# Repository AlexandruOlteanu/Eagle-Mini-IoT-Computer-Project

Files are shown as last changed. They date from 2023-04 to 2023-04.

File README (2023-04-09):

<Copyright Alexandru Olteanu, grupa 332CA, alexandruolteanu2001@gmail.com>

    Proiectul a fost unul interesant, nu regret ca am invatat cat de cat cum 
se proiecteaza o placuta. Schema a fost relativ usor de construit, doar 
unele componente precum Pinhead-ul cu 6 pini au trebuit luate din alte 
biblioteci, In rest procesul a mers destuld e ok.
    La construirea board-ului a fost mai mult de lucru, a durat ceva pana
am pus dimensiunile placutei, unde vin gaurile si usb-ul ce iese afara, apoi
punerea strategica a componentelor incat:
    a) sa incapa
    b) condensatoarele sa fie apropiate de pinii majoritatii componentelor la 
care sunt conectati
    c) Fiecare rezistenta sa fie pusa cat mai central intre componentele legate
la ea.
    In continuarea, la tragerea cablurilor a fost nevoie de mai multe rectificari
pana sa ajung la varianta finala, am avut diverse probleme de overlap, fire care
nu mai mergeau trase din cauza altora, etc.
    Per total, o tema faina dar muncitoreasca, thx!

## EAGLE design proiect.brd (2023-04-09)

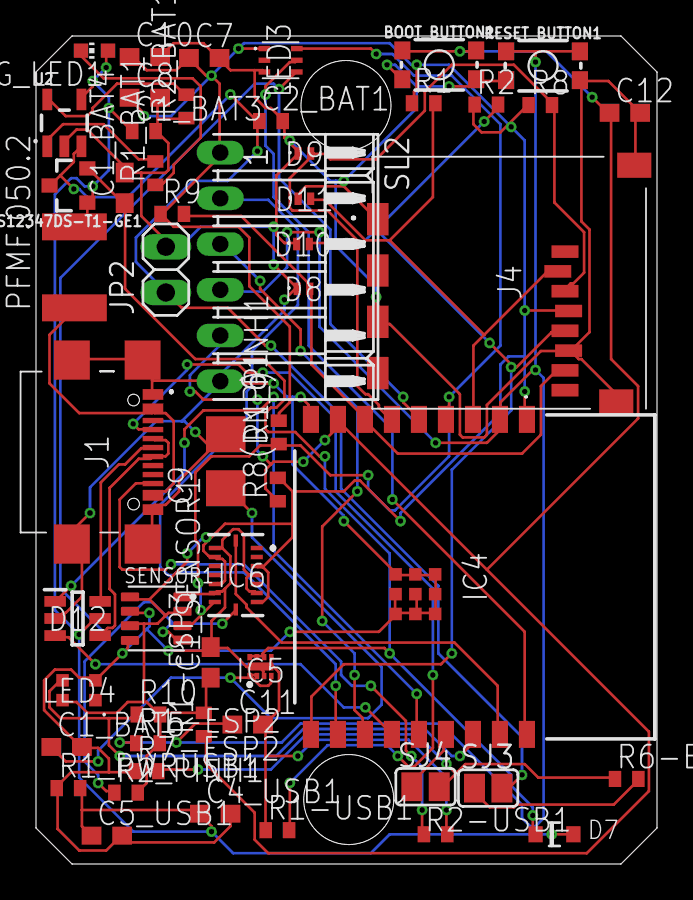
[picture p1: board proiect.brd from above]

Board: 2 copper layers, 34.5 x 46.0 mm, 54 parts (0 on the bottom side), 32 nets.

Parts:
BOOT_BUTTON1: ESP32_WROVER_SPARKFUN-SWITCHES_TACTILE_SWITCH_SMD_4.6X2.8MM
C1_BAT3, C2_BAT1: 4.7uF; ESP32_WROVER_EAGLE-LTSPICE_C0402
C1_BAT4, C1_BAT5, C5_USB1: 4.7uF; ESP32_WROVER_RCL_C0603
C1_SENSOR1, C4_USB1, C7, C8, C10, C12: 100nF; ESP32_WROVER_RCL_C0603
C9: 100uF TANT; RCL_CT3528
C11: 1uF; ESP32_WROVER_RCL_C0603
CHG_LED1: ESP32_WROVER_ADAFRUIT_CHIP-LED0603
D7: ESP32_WROVER_AVX---SD0805S020S1R0_AVX_SD0805S020S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; ESP32_WROVER_AVX---SD0805S020S1R0_AVX_SD0805S020S1R0_0
D8, D9, D10, D11: PESD3V3S1BLYL; SAMACSYS_PARTS_PESD5V0S1BL315
D12: USBLC6-2SC6Y; SAMACSYS_PARTS_SOT95P280X145-6N
IC4: ESP32-C3-WROOM-02-H4; SAMACSYS_PARTS_ESP32C3WROOM02H4
IC5: NCP186BMX330TAG; SAMACSYS_PARTS_NCP186AMX330TAG
IC6: BMI085; SAMACSYS_PARTS_BMI085
J1: USB4110-GF-A; SAMACSYS_PARTS_USB4110GFA
J4: 112A-TAAR-R03_ATTEND; SAMACSYS_PARTS_112ATAARR03ATTEND
JP2: PINHEAD_1X02
LED3: LTR308; ESP32_WROVER_SAMACSYS_PARTS_LTR303ALS01
LED4: WS2812B-2020; SAMACSYS_PARTS_WS2812B2020
PFMF.050.2: 500mA; ESP32_WROVER_VARISTOR_CT/CN1812
R1, R1-ESP2, R1-ESP3, R2, R2_PINH1, R8, R8(DNP)1, R9, R10: 10K; ESP32_WROVER_EAGLE-LTSPICE_R0402
R1-USB1, R2-USB1: 5K1; ESP32_WROVER_EAGLE-LTSPICE_R0402
R1_BAT1: 200; ESP32_WROVER_EAGLE-LTSPICE_R0402
R1_PINH1: 10k; ESP32_WROVER_EAGLE-LTSPICE_R0402
R1_PWRUSB1, R6-ESP2, R7-ESP2: 100K; ESP32_WROVER_EAGLE-LTSPICE_R0402
R2_BAT1: 2K; ESP32_WROVER_EAGLE-LTSPICE_R0402
RESET_BUTTON1: ESP32_WROVER_SPARKFUN-SWITCHES_TACTILE_SWITCH_SMD_4.6X2.8MM
S12347DS-T1-GE1: 20V/4.2A/52mΩ/1.4W; ESP32_WROVER_SPARKFUN-DISCRETESEMI_SOT23-3
SENSOR1: BME680; ESP32_WROVER_BME680_PSON80P300X300X100-8N
SJ3, SJ4: JUMPER_SJ
SL2: 06PA
U2: MCP73831; ESP32_WROVER_SPARKFUN-IC-POWER_SOT23-5

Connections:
3V1: C1_SENSOR1.1, C7.1, C8.1, C10.1, IC4.1, IC6.3, IC6.7, IC6.11, IC6.14, J4.P4, LED3.1, LED4.4, R1.1, R1-ESP2.2, R1-ESP3.2, R1_PINH1.2, R2.1, R2_PINH1.2, R8.1, R8(DNP)1.2, R9.1, R10.2, SENSOR1.2, SENSOR1.6, SENSOR1.8, SL2.1
A2: IC4.15, SJ4.1
BOOT1: BOOT_BUTTON1.3, BOOT_BUTTON1.4, C12.1, IC4.8, R1-ESP3.1, R8(DNP)1.1, SL2.5
D+1: D12.1, IC4.14
D-1: D12.3, IC4.13
DN1: D12.4, J1.A7, J1.B7
DP1: D12.6, J1.A6, J1.B6
GND1: BOOT_BUTTON1.1, BOOT_BUTTON1.2, C1_BAT3.2, C1_BAT4.2, C1_BAT5.2, C1_SENSOR1.2, C2_BAT1.2, C4_USB1.2, C5_USB1.2, C7.2, C8.2, C9.-, C10.2, C11.2, C12.2, D8.1, D9.1, D10.1, D11.1, D12.2, IC4.9, IC4.19, IC4.20, IC4.21, IC4.22, IC4.23, IC4.24, IC4.25, IC4.26, IC4.27, IC5.3, IC5.5, IC5.9, IC6.4, IC6.6, IC6.10, IC6.15, J1.A1, J1.A12, J1.B1, J1.B12, J1.MP1, J1.MP2, J1.MP3, J1.MP4, J4.G1, J4.G2, J4.G3, J4.G4, J4.P6, JP2.2, LED3.3, LED4.2, R1-USB1.1, R1_PWRUSB1.1, R2-USB1.2, R2_BAT1.1, R7-ESP2.1, RESET_BUTTON1.1, RESET_BUTTON1.2, SENSOR1.1, SENSOR1.5, SENSOR1.7, SL2.6, U2.2
GPIO2: IC4.18, LED3.5
GPIO3: IC4.17, IC6.16
MISO1: D8.2, IC4.7, J4.P7, R9.2
MOSI1: D9.2, IC4.6, J4.P3, R8.2
unnamed: J1.A5, R1-USB1.2
unnamed: J1.B5, R2-USB1.1
unnamed: C1_BAT4.1, D7.1, IC5.6, IC5.7, IC5.8, S12347DS-T1-GE1.2
unnamed: C1_BAT5.1, C9.+, IC5.1, IC5.2, IC5.4
unnamed: R6-ESP2.2, SJ3.1
unnamed: R6-ESP2.1, R7-ESP2.2, SJ4.2
unnamed: R1_BAT1.2, U2.1
unnamed: CHG_LED1.C, R1_BAT1.1
unnamed: R2_BAT1.2, U2.5
NEOPIXEL1: IC4.16, LED4.3, R10.1
RESET1: C11.1, IC4.2, R1-ESP2.1, RESET_BUTTON1.3, RESET_BUTTON1.4, SL2.4
RX1: IC4.11, SL2.2
SCK1: D10.2, IC4.10, J4.P5, R2.2
SCL1: IC4.5, IC6.8, LED3.4, R2_PINH1.1, SENSOR1.4
SDA1: IC4.4, IC6.9, LED3.6, R1_PINH1.1, SENSOR1.3
SS1: D11.2, IC4.3, J4.P2, R1.2
TX1: IC4.12, SL2.3
VBAT1: C2_BAT1.1, JP2.1, S12347DS-T1-GE1.3, SJ3.2, U2.3
VBUS1: C1_BAT3.1, C4_USB1.1, C5_USB1.1, CHG_LED1.A, D7.2, D12.5, PFMF.050.2.2, R1_PWRUSB1.2, S12347DS-T1-GE1.1, U2.4
VUSB1: J1.A4, J1.A9, J1.B4, J1.B9, PFMF.050.2.1
